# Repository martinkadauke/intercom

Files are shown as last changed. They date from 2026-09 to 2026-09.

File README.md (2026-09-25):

# Klingelbox

**An open-hardware door intercom: a brass front flush in the facade, an e-paper touch screen,
two-way talk, and one PoE cable. Built on ESP32, ESPHome and Home Assistant. No camera, ever.**

[Deutsch](README.de.md)

> Status: prototype. The parts are on the bench, the front and the box exist as 3D-printed
> prototypes. Nothing is installed at a door yet. State of this page: 24 September 2026.

<p align="center">
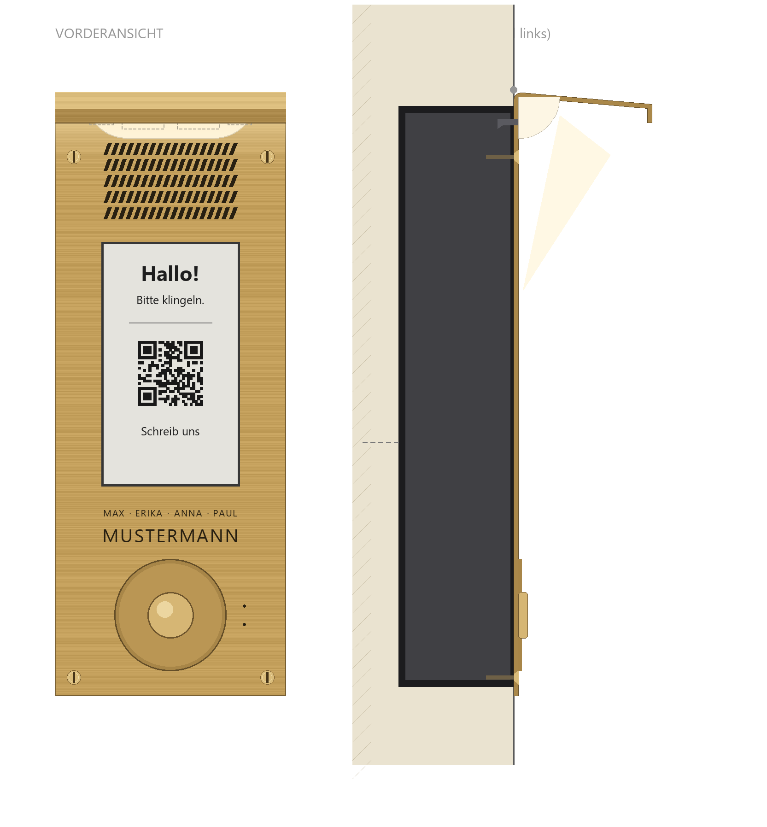
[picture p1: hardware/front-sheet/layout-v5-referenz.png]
Front view and side section of the brass front: speaker grille, portrait e-paper screen, engraved names, round brass button, folded rain roof with a light band
  
</p>

## What it is

- **A doorbell first.** A plain brass button on a supervised line: idle, pressed and a cut wire
  read as three different voltages, so a broken wire is reported instead of going silent. The
  ring reaches the phone before anything else happens at the door.
- **A screen at the door.** A 4.7" e-paper touch screen behind a window in the brass: greetings,
  notices, a QR code. It keeps its image without power and stays readable in sunlight.
- **Talk.** A microphone and a speaker behind the brass for two-way conversation, relayed
  through Home Assistant to a phone. Planned: voice messages and push-to-talk into the house.
- **One cable.** Data and power arrive over a single outdoor PoE cable. No power supply at the
  door, no switch in the box.
- **Local.** Everything runs on ESPHome and Home Assistant at home.
- **Private by design.** No camera. The microphone only opens after a visitor presses
  something, and the screen says so.

## Explore it

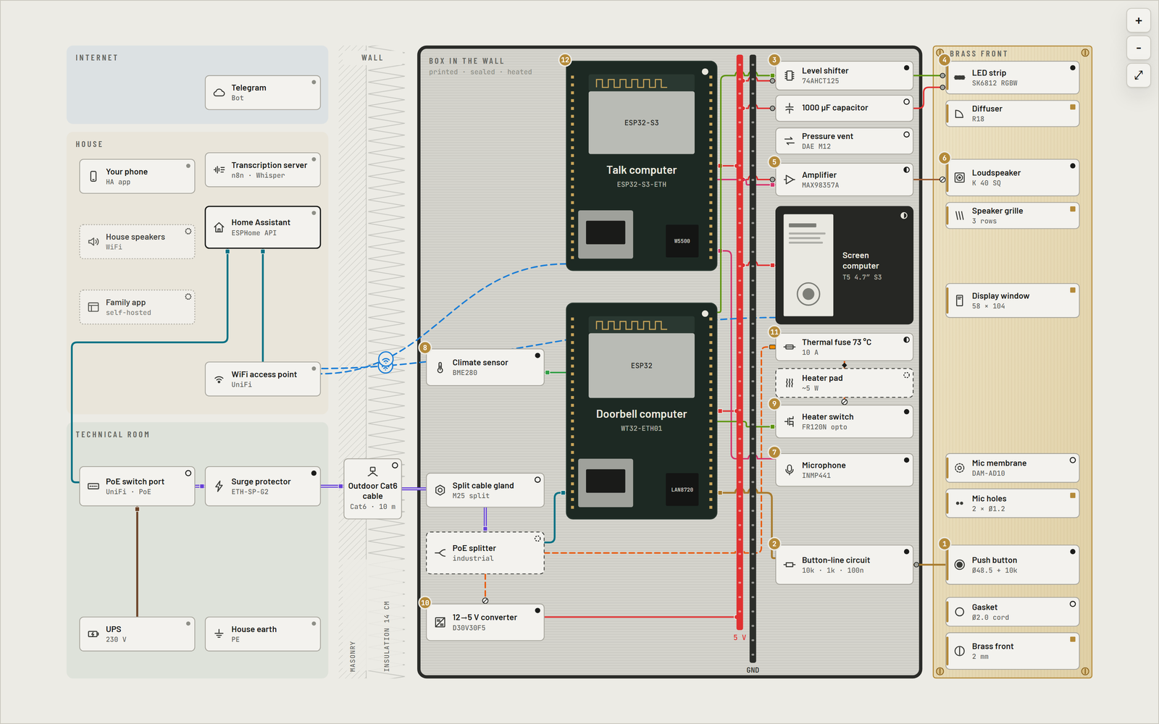
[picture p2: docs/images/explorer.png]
The explorer: every part of the intercom from the house network through the wall into the box and the brass front, with colour-coded wires


The [explorer](explorer/) is an interactive map of the whole system: switch wire types on and
off, tap any part for what it is and why it was chosen, and follow walkthroughs of a ring, the
power path, winter heating and a call. Download
[`explorer/dist/klingelbox-explorer.html`](explorer/dist/klingelbox-explorer.html) and open it in
a browser. A hosted version is planned.

## How it works

Three small computers share one cable and one 5 V rail, and nothing else:

| Computer | Board | Link | Job |
|---|---|---|---|
| Doorbell | WT32-ETH01 | wired | button line, light, heater, climate sensor |
| Talk | Waveshare ESP32-S3-POE-ETH | WiFi | microphone, amplifier, calls |
| Screen | LilyGO T5-4.7-S3 Touch | WiFi | e-paper touch screen |

The bell runs on its own board with stock ESPHome only, so a crash or an update in the audio code
can never silence it. Details, power budget and the winter heater: [docs/architecture.md](docs/architecture.md).

## Repository

| Path | What |
|---|---|
| [`docs/architecture.md`](docs/architecture.md) | how it works, power, winter, talk, mechanics |
| [`docs/bom.md`](docs/bom.md) | what to buy, with the traps (fake "touch" listings, copper-clad cable) |
| [`docs/roadmap.md`](docs/roadmap.md) | the milestones from parts on the desk to the door, and the decisions still to lock in |
| [`docs/build-log.md`](docs/build-log.md) | what happened so far, including the dead ends |
| [`docs/family-app.md`](docs/family-app.md) | the planned self-hosted app for the household |
| [`hardware/`](hardware/) | front sheet, box and diffuser: generator scripts, STL and STEP, part drawings |
| [`explorer/`](explorer/) | the interactive map and its build |
| [`tools/`](tools/) | the privacy scan that runs before every push |

Firmware (ESPHome YAML) and the Home Assistant automations will be added once they have
passed the bench tests.

## Safety

- The surge protector only protects when it is earthed. That, and anything on 230 V, is a job
  for an electrician.
- The e-paper panel is rated 0 to +50 °C. Outdoors it needs the heater, and the heater needs
  its thermal fuse.
- Never plug a board's USB into a computer while the box's 5 V rail is live, unless the cable
  blocks power.

## Licences

- Code (scripts, explorer, firmware): [MIT](LICENSE)
- Hardware designs (CAD scripts, STL, STEP, drawings): [CERN-OHL-P-2.0](LICENSES/CERN-OHL-P-2.0.txt)
- Documentation and images: [CC BY 4.0](LICENSES/CC-BY-4.0.txt)

Designed and written with [Claude Code](https://claude.com/claude-code).

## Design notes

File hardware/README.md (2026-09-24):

# Hardware

Everything physical: the brass front, the box in the wall, the diffuser and dimensioned drawings
of the bought parts. All models are generated by scripts, so dimensions live in code, not in
hand-edited meshes.

## Folders

| Folder | What |
|---|---|
| [`front-sheet/`](front-sheet/) | `make_layout_v5.py` draws the front at true scale (1 unit = 1 mm): a dimensioned SVG, a reference PNG and a detail of the fold. The SVG also carries the engraving, which the CAD reads. |
| [`cad/`](cad/) | FreeCAD scripts. `kasten_v3_params.py` is the single source of dimensions for box and front; `make_kasten_v3.py` builds the box and carrier plate, `make_diffusor_v1.py` the diffuser, `make_sheet_v5.py` the front sheet. |
| [`models/`](models/) | Exported STL (for printing) and STEP (for CAD and metal shops). |
| [`parts/`](parts/) | Dimensioned drawings of bought parts, from datasheets and community measurements. |

## Models

| File | Part | Print notes |
|---|---|---|
| `models/front-sheet-v5.step` | brass front, master | send this to a metal shop (2 mm brass, laser-cut, folded) |
| `models/front-sheet-v5_print.stl` | front, one piece, back on the bed | needs a bed diagonal of about 260 mm |
| `models/front-sheet-v5_print_front.stl` + `_roof.stl` | front split in two, with a lap joint and pegs | both fit side by side on a 256 × 256 bed |
| `models/box-v3_print.stl` | box that sits in the facade | ASA |
| `models/carrier-plate-v3_print.stl` | plate the electronics mount on | ASA |
| `models/diffuser-v1.step`, `diffuser-v1_print.stl` | quarter-round light diffuser | translucent filament |
| `models/diffuser-test-plate.stl` | test plate for the diffuser fit | |

The CAD comments are in German, as the project was designed in German.

## The engraving is a placeholder

The public front carries **MAX · ERIKA · ANNA · PAUL / MUSTERMANN**. To engrave your own names:

1. Edit `NAMES` and `FAMILY` at the top of `front-sheet/make_layout_v5.py`. Longer surnames are set
   smaller rather than squeezed.
2. Run it (needs Python with Pillow and fontTools; it uses the Segoe UI font that ships with
   Windows, which is **not** included here):
   ```
   python front-sheet/make_layout_v5.py
   ```
3. Rebuild the sheet with FreeCAD's command-line interpreter:
   ```
   cd cad
   freecadcmd build_front_sheet.py
   ```
   The results land in `cad/out/`.

## Measure before you commit

Several parts have dimensions nobody publishes (mounting holes of the display board, the
WT32-ETH01, module heights). The drawings in `parts/` mark them. The box design is on its
third iteration and will change once the real parts are measured.

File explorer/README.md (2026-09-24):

# Explorer

An interactive map of the whole system: every part, every wire type as a switchable layer,
every joint and solder spot, and step-by-step walkthroughs (a ring, the power path, winter,
the light, a call). English and German, light and dark, works on a phone.

**Open it:** download [`dist/klingelbox-explorer.html`](dist/klingelbox-explorer.html) and open
it in a browser. It is one self-contained file; the only outside request is for web fonts.

## How it is built

| File | Role |
|---|---|
| `skeleton.json` | the structure and the single source of truth: zones, wire layers, parts (with status), connections, walkthroughs, solder jobs, open points |
| `layout.json` | where each part sits on the 1600 × 1000 canvas, short type tags, and route hints for wires that need them |
| `texts.json` | the English and German copy for every part, wire, walkthrough and solder job |
| `template.html` | page, styles and the rendering engine (plain JavaScript, no libraries) |
| `build.py` | merges the four into `dist/klingelbox-explorer.html` |

```
python build.py
```

The build checks every reference first (a part without a position, a wire to an unknown part,
a walkthrough step naming a missing wire) and writes nothing if one is broken.

Wires are routed automatically: each connection picks the facing sides of its two parts, ends
are spread along each side, straight runs are preferred, and wires that cross a supply bar hop
over it. Where the automatic route is not good enough, `layout.json` pins the ends or gives
waypoints.

To change the system, edit `skeleton.json` (structure) and `texts.json` (words), then rebuild.

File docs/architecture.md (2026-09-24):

# Architecture

State: 2026-09-24. Prototype stage: parts are on the bench, nothing is installed at the door yet.

The interactive version of this page is the [explorer](../explorer/). It shows every part, wire,
joint and solder spot, and walks through what happens on a ring, in winter, at dusk and during a call.

## The idea in one picture

```
 house network                 technical room                wall           box in the facade          brass front
 ─────────────                 ──────────────                ────           ─────────────────          ───────────
 Home Assistant ── LAN ── PoE switch (on a UPS) ── surge ── one outdoor ── cable ── PoE splitter ─┬─ data ─ doorbell computer ── button, light, heater, sensor
       │                                         protector   Cat6 cable    gland        │         │
       │                                          (earthed)                             │         └─ DC ─── 5 V rail ── talk computer ── mic, amplifier, speaker
       │                                                                                │                        └──── screen computer ── 4.7" e-paper touch
       └──────────────── WiFi access point ~1 m away ···· radio ···· talk + screen computers
```

- **One cable.** A single ready-made outdoor Cat6 cable carries data and power (PoE, about 48 V)
  from the switch into the box. There is no power supply at the door and no switch in the box.
- **Three small computers, each with one job.** They share only power and ground; no signal
  wires run between them.

| Computer | Board | Link | Job |
|---|---|---|---|
| Doorbell computer | WT32-ETH01 (ESP32 + LAN8720) | wired, on the splitter's data port | button line, light, heater, climate sensor, power governor |
| Talk computer | Waveshare ESP32-S3-POE-ETH | WiFi | microphone, amplifier, two-way talk |
| Screen computer | LilyGO T5-4.7-S3 Touch (H716) | WiFi | 4.7" e-paper touch screen behind the brass window |

Why three and not one: the bell is the one function that must never fail. A crash or an update
in the audio code cannot take it down when it runs on its own board with stock ESPHome only.
The e-paper panel is a parallel panel that needs its own driver board anyway.

## The ring path (the part that must always work)

1. The brass button sits on a **supervised line**: 10 kΩ pull-up to 3.3 V, 1 kΩ series resistor,
   100 nF to ground, and a 10 kΩ end-of-line resistor soldered straight across the button.
   That gives three distinct voltages on an analog (ADC1) input:

   | State | Voltage |
   |---|---|
   | idle | about 1.73 V |
   | pressed | about 0.30 V |
   | wire cut | about 3.1 to 3.3 V |

   A cut or corroded wire is reported instead of going silent. The pull-up exists because a
   floating input on the first prototype produced 134 phantom rings in 15 minutes.
2. The doorbell computer samples every 40 ms and confirms a press with a median filter
   (about 80 to 120 ms).
3. It sends the ring event **first**, over the cable, to Home Assistant, which pushes a
   high-priority notification to the phone (target: under 1 second, not yet measured).
4. Only then does the door give local feedback: the light flashes, the screen changes.
   Nothing on the ring path waits for the screen, the talk computer or WiFi.

## Power

| Stage | Detail |
|---|---|
| Switch port | PoE on, switch on a UPS so a short power cut does not stop the bell |
| Surge protector | Ubiquiti ETH-SP-G2 before the outdoor cable; only works when earthed (electrician's job) |
| Splitter | industrial, rated down to -40 °C; output **12 V or 5 V still undecided** |
| 12 → 5 V | Pololu D30V30F5 step-down (only with a 12 V splitter) |
| 5 V rail | lever clamps feed all three computers, the amplifier, the level shifter and the LED strip |
| 3.3 V | made on the doorbell and talk computers for the sensor, the button pull-up and the microphone |
| Heater | about 5 W pad behind the display, through a 73 °C one-shot thermal fuse, switched low-side by an opto-coupled MOSFET module |

**Budget.** The surge protector's datasheet lists 802.3af, which allows 12.95 W at the device.
A ring plus a call with the heater on comes to roughly 12.1 W (an estimate, not measured), so the
doorbell computer runs a **governor**: heater off during calls and for 5 minutes after a press,
LED brightness capped while it heats.

## Winter

The e-paper panel is rated 0 to +50 °C; the box sees frost. A BME280 in the box reads
temperature and humidity. The heater **fails cold**: off at boot, off if the sensor fails,
firmware cut-off around 40 °C, and the thermal fuse as the last line of defence. Below about
+2 °C the screen does not refresh.

## Two-way talk (chosen, not yet proven)

- Software: the community [VoIP Stack for ESPHome](https://github.com/n-IA-hane/esphome-intercom)
  with its Home Assistant integration (via HACS). Home Assistant acts as the SIP router and
  hands the call to the phone.
- Flow: ring → Home Assistant starts a call to the talk computer → the phone gets a notification
  with a talk button → tapping it answers. Receiving the notification never opens a microphone.
- Audio: INMP441 MEMS microphone, MAX98357A I²S amplifier at its lowest gain (100 kΩ from GAIN to
  Vin), VISATON K 40 SQ speaker (82 dB at 1 W / 1 m, rated 0.5 W).
- If the echo cannot be tuned out: walkie-talkie mode with the stack's mute switches.
- **Security:** the stack's SIP endpoint has no authentication or encryption. The door devices
  belong in their own VLAN with a firewall that only lets Home Assistant reach them, and
  auto-answer stays locked off.
- **Privacy:** the microphone only opens after a visitor presses something, it is announced on the
  screen and by the LED colour, nothing is recorded without that. (In Germany, § 201 StGB makes
  recording the spoken word without consent a criminal offence.)

Not designed yet: push-to-talk into speakers inside the house, and voice messages delivered to
a phone as audio plus a local Whisper transcript.

## Mechanics

- **Front:** one 2 mm brass sheet, 100 × 260 mm, with a folded rain roof and drip edge. It is
  held by four slotted brass countersunk screws (M3, DIN 963). Cut-outs: display window, speaker
  grille (3 rows of slanted slots), 2 × Ø1.2 mm mic holes and the button hole (Ø49.5 mm for a
  Ø48.5 mm ring). The LED band sits in the bend: 2 windows for the strip and 2 slits for the
  diffuser's tabs.
- **Box:** 3D-printed (ASA; PETG on open-frame printers, which warp large ASA parts), set flush
  into 14 cm of facade insulation and fixed into the masonry behind it. Gasket cord in a rim groove, pressed by the front. A pressure vent lets it breathe
  into the grille cavity; the grille cavity counts as outside air and has to drain.
- **Cable entry:** a split cable gland (Conta-Clip KDS-KV M25, 25.2 mm hole) with a split
  sealing insert for the 6–7 mm cable, so the ready-made cable with its moulded plug can go
  through.
- **No camera. Ever.** This is a design rule, not an open question.

## Open points

See the "Still open" list in the explorer. In short: splitter voltage, real power draw, pin
assignment on the bench, WiFi signal inside the box, the LED strip type and the screen's touch
chip, and a CAD fix (the grille cavity floor slopes the wrong way).

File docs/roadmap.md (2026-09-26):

# Roadmap

State: 2026-09-26. Generated from `explorer/skeleton.json` and `explorer/texts.json`;
the interactive version is the roadmap section of the [explorer](../explorer/).

`[x]` done · `[~]` under way · `[ ]` to do · `◆` a decision that must be locked in

## Must-lock-ins

- ◆ Lock in: splitter 12 V or 5 V (it decides the heater and its switch) (M1)
- ◆ Lock in: the box's inside size (the 12 V splitter alone is 104 × 82 × 32 mm) (M2)
- ◆ Lock in: full duplex or walkie-talkie, after tuning the echo (M3)
- ◆ Lock in: which extra audio features (voice messages, push-to-talk into the house) (M3)
- ◆ Lock in: flush in the wall (cut into the insulation) or on the wall (printed box inside a brass housing) (M4)
- ◆ Lock in: box material (ABS is here for test boxes; ABS and ASA warp in large parts on an open printer, PETG is the alternative) (M4)

## M0 · Concept and architecture

**Done** · 4 of 4 tasks done

Decide what the device is before buying and printing: the front design, the parts and how they connect.

- [x] Front design v5: one bent brass sheet, 100 × 260 mm, light band under the roof
- [x] Architecture: one PoE cable, three computers (doorbell, talk, screen)
- [x] Parts chosen and drawn with their dimensions
- [x] This map and the public repository

*Done when:* Every part, wire and open decision is on the map.

## M1 · All hardware on the table

**Now** · 1 of 5 tasks done

Nothing can be measured, fitted or programmed for real until every part of the final build is here.

Needs: M0 Concept and architecture

- [ ] ◆ Lock in: splitter 12 V or 5 V (it decides the heater and its switch)
- [ ] Place the order: cable, cable gland, heater, seals, small parts
- [x] In hand: doorbell and talk computers, microphones, amplifier, speaker, 12→5 V converter, level shifter, climate sensor, heater switch, USB-serial adapter, thermal fuses
- [~] In the mail: the screen computer
- [ ] Bench checks on arrival: touch chip (I²C scan), LED strip really RGBW, heater switch triggers at 3.3 V

*Done when:* Every part of the final build is here and identified.

## M2 · Measure and alpha print

**Next** · 0 of 5 tasks done

Find out whether everything fits before designing the real box: first the parts alone, then with every cable.

Needs: M1 All hardware on the table

- [ ] Measure everything the makers don't publish: display mounting holes, board heights, microphone, splitter
- [ ] Count every cable and connector that enters the box
- [ ] Alpha print 1: all parts in place, no cables
- [ ] Alpha print 2: the same with all the internal wiring
- [ ] ◆ Lock in: the box's inside size (the 12 V splitter alone is 104 × 82 × 32 mm)

*Done when:* Every part and every cable fits in a printed box, and the number of cables entering it is final.

## M3 · Bench build and software

**Now** · 0 of 8 tasks done

Wire everything together on the desk and build the software until the experience at the door and on the phone is release quality. The first two steps can start today.

Needs: M1 All hardware on the table

- [ ] Phone side first: answer a test call from a notification (no door hardware needed)
- [ ] Doorbell on the doorbell computer: all three line states, 20 of 20 presses on the phone in under 1 s
- [ ] (waiting) Screen pages change on a ring; WiFi signal measured in a mock box behind metal (waits for the screen)
- [ ] Talk, one direction at a time (walkie-talkie)
- [ ] ◆ Lock in: full duplex or walkie-talkie, after tuning the echo
- [ ] ◆ Lock in: which extra audio features (voice messages, push-to-talk into the house)
- [ ] (waiting) One cable, power rail, heater and its power limit; measure the real PoE draw (waits for the splitter)
- [ ] UX until release quality: screen pages, light, sounds, the flow on the phone

*Done when:* The desk setup does everything at release quality, and the measured power stays within 802.3af.

## M4 · Watertightness proof of concept

**Now** · 0 of 7 tasks done

Prove that the printed box, a steel bracket and a metal plate can be sealed, whichever way the box is mounted. Exploratory: it runs alongside everything else.

Needs: M0 Concept and architecture

- [ ] ◆ Lock in: flush in the wall (cut into the insulation) or on the wall (printed box inside a brass housing)
- [ ] Design and source the steel bracket the brass plate screws onto
- [ ] Test plate: flat, no bends, no engraving, but the real cut-outs
- [ ] Seals: 2 mm gasket cord, button O-ring, mic membranes, cable gland, pressure vent
- [ ] ◆ Lock in: box material (ABS is here for test boxes; ABS and ASA warp in large parts on an open printer, PETG is the alternative)
- [ ] The grille cavity drains outwards (the CAD slope is currently the wrong way round)
- [ ] Water test of a sealed test box: hose or shower, dry inside afterwards

*Done when:* A test box with bracket and test plate stays dry inside in a repeatable water test, and the sealing recipe is written down.

## M5 · Beta box on the desk

**Later** · 0 of 4 tasks done

The complete device in its real box, with the steel bracket and a dummy plate, running on the desk over Ethernet. Not watertight yet.

Needs: M2 Measure and alpha print, M3 Bench build and software, M4 Watertightness proof of concept (bracket and dummy plate)

- [ ] Print the beta box from what the alpha prints showed
- [ ] Fit the steel bracket and a dummy plate (flat, same cut-outs)
- [ ] All inside wiring finished; the wiring to the outside is settled
- [ ] Two weeks on the desk over Ethernet: scripted rings and calls, 20 PoE power cycles, no unexpected reboot of the doorbell computer

*Done when:* The whole device runs in its box for two weeks without a surprise.

## M6 · Pre-release box

**Later** · 0 of 5 tasks done

Bring the sealing lessons into the proven beta design and order the real brass front.

Needs: M5 Beta box on the desk, M4 Watertightness proof of concept

- [ ] Apply the sealing recipe to the beta design
- [ ] Order the real brass front from a metal shop (laser-cut, bent, engraved)
- [ ] Final print in the chosen material
- [ ] Water test of the complete device
- [ ] Freezer cold start: heater, screen and splitter come up in frost

*Done when:* The finished device passes the water test and the cold start.

## M7 · At the door

**Later** · 0 of 4 tasks done

Install the finished device at the front door and switch it on for good.

Needs: M6 Pre-release box

- [ ] Electrician: earth the surge protector, remove the old bell transformer
- [ ] Cable route through the wall
- [ ] Mount the box and seal the joint to the facade
- [ ] Go live with the watchdogs on (stuck button, cut wire, offline)

*Done when:* A ring at the real door reaches the phone.

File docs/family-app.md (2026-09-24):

# The family app (planned, nothing built yet)

The door is not meant to be configured through YAML files forever. The plan is a small,
self-hosted web app that the household uses day to day, while Home Assistant stays the
automation hub underneath.

## What it should do

- **Screen notices:** put a message on the door's e-paper screen ("Back in 20 minutes",
  "Parcels please to the neighbours"), with an expiry time.
- **Chimes:** choose the ringtone that plays on the speakers inside the house, and its volume,
  per room and per time of day.
- **Silence:** a quiet mode that routes rings to a quiet notification channel.
- **Other home systems and speakers:** one interface instead of several apps.
- **Talk (later):** could host the relay for live push-to-talk from the door into the house.

## How it connects

```
 household (browser / phone) ──► family app ◄──► Home Assistant ◄──► door computers (ESPHome)
                                      ▲                 │
                                      └── status & ─────┘
                                          control API
```

- The app exposes an **API and a Home Assistant integration**, so every setting it owns is also
  visible to automations (status and control).
- The door firmware keeps its settings reachable over ESPHome entities and services instead of
  burying them in firmware. That is a constraint on the firmware today, even though the app
  comes later.
- Self-hosted, no cloud dependency; accounts only for the household.

## Open questions

- Framework and hosting (it will run next to Home Assistant on the home server).
- Whether the push-to-talk relay lives in the app or in Home Assistant.
- How screen notices avoid telling strangers that nobody is home.

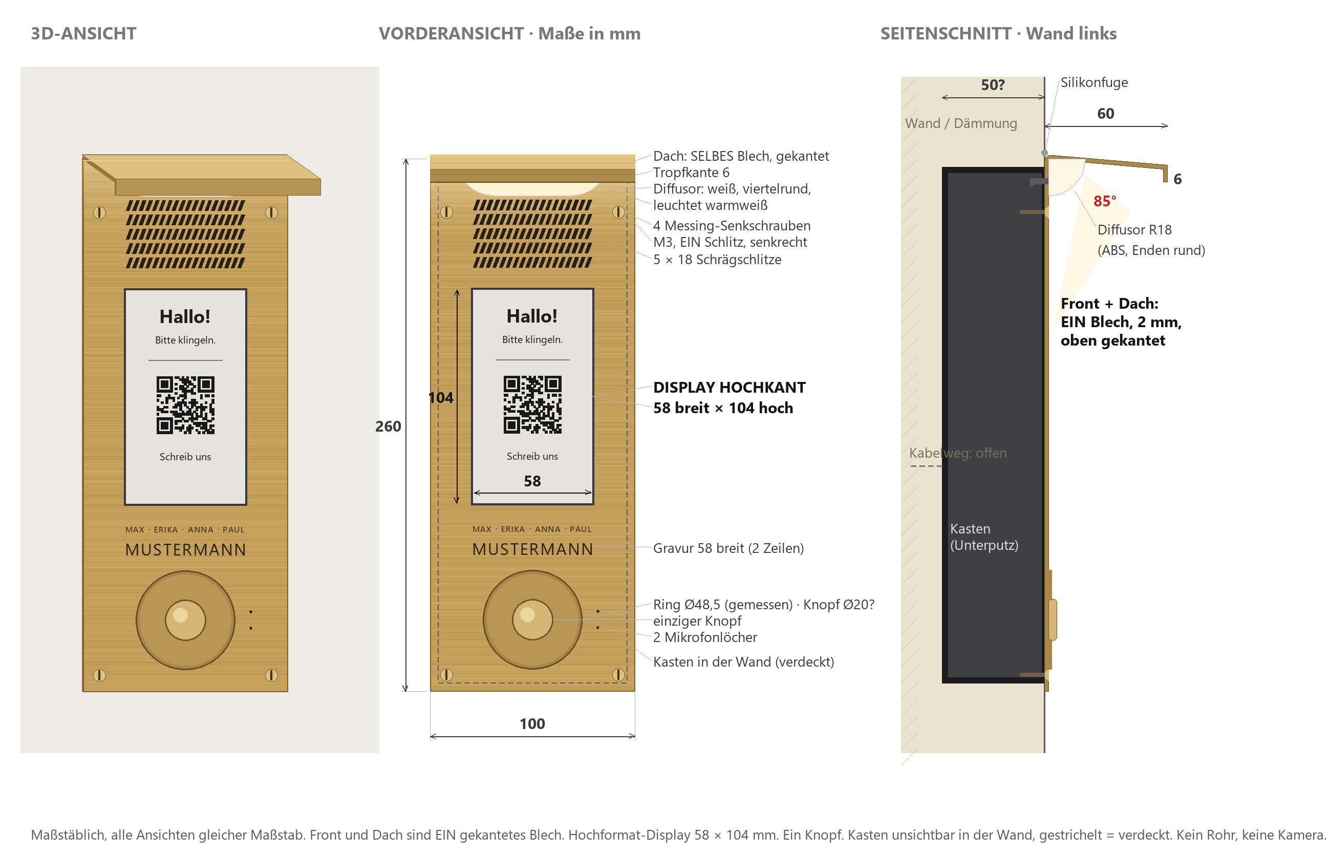
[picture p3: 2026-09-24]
hardware/front-sheet/gemini-zeichnung-v5.png

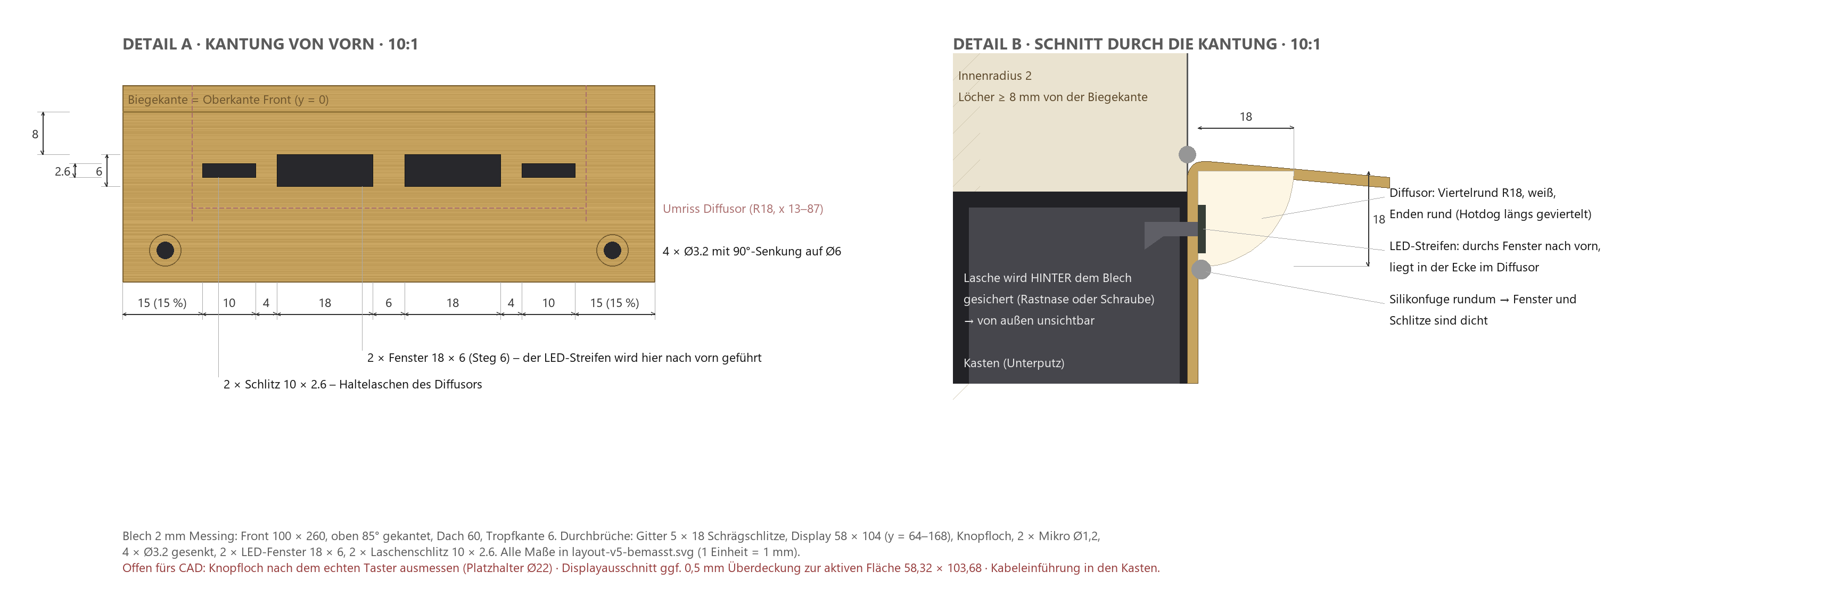
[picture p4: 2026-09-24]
hardware/front-sheet/detail-kantung-v5.png

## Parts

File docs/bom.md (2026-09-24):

# What to buy (bill of materials)

State: 2026-09-24. Prices are gross, from German/EU shops, and were read off the product pages on
that date. "Pending" means the choice is not made yet; do not buy those blind.

Parts marked **measure** have dimensions the maker does not publish. The drawings in
[hardware/parts](../hardware/parts/) show what is known and what still has to be measured.

## Indoors: network and power

| Qty | Part | Why | Notes |
|---|---|---|---|
| 1 | PoE switch port, 802.3af or better | data + power down one cable | put the switch on a UPS |
| 1 | Ubiquiti ETH-SP-G2 surge protector | protects the house network from the outdoor cable | **must be earthed by an electrician**; datasheet lists 802.3af only |
| 1 | Short patch cable | switch → surge protector | |

## Through the wall

| Qty | Part | Why | Notes |
|---|---|---|---|
| 1 | Ready-made outdoor Cat6 cable, goobay **55432** (10 m) | the one cable | solid copper AWG 24/1, U/UTP, double PE jacket, UV-resistant, -40 to +75 °C, outer Ø 6.0–6.6 mm; about €11–13. **Not** goobay 94389: almost the same title, but copper-clad aluminium |
| 1 | Split cable gland Conta-Clip KDS-KV M25 BK (28611.4) | lets the moulded plug through, then seals | lock nut included; Conta-Clip gives a **25.2 mm** hole; IP66 |
| 1 | Split sealing insert Conta-Clip KDS-DE 6-7 BK (28526.4) | seals around one 6–7 mm cable | measure your cable: 5-6 BK (28525.4) and 7-8 BK (28527.4) are the neighbours. Use BK (UV-stabilised), not GR |

## In the box: power

| Qty | Part | Why | Notes |
|---|---|---|---|
| 1 | Industrial PoE splitter, rated down to -40 °C | separates data and power | **pending** — see below |
| 1 | Pololu D30V30F5 step-down 12 → 5 V, 3.4 A | 5 V rail | only with the 12 V splitter |
| 1 set | Lever clamps (WAGO 221) | 5 V and ground distribution | |
| 1 | Short Cat6 patch cable, 0.25 m, copper | splitter → doorbell computer | some cheap 0.25 m cables are CCA too |
| 1 | USB-C plug to 2-pin screw terminal (VBUS/GND only) | 5 V into the screen computer | no data lines, no CC resistor: fine for feeding power *into* the board; check polarity first |
| 2 | Resettable PTC fuse, 0.5 A hold (e.g. FREI PFRA 050) | protects the rail from the LED branch | 0.5 A covers the ~4 LEDs used |
| 2 | 1000 µF / 25 V low-ESR and 10 µF electrolytic capacitors | at the LED strip and at the amplifier | stripe = minus |

**The splitter decision**

| | 12 V: TRENDnet TI-SG104 | 5 V: Waveshare industrial PoE splitter |
|---|---|---|
| Price seen | about €69–70 | €33.99 (DC plug) |
| Temperature | -40 to +75 °C | -40 to +85 °C |
| Size | 104 × 82 × 32 mm | 102.5 × 29.6 × 24.8 mm |
| DC output | 4-pin screw terminal | pigtail with a DC barrel plug (reviews disagree whether it is 5.5 × 2.1) or a USB-C variant |
| Power from 802.3af | 10.2 W at 12 V (TRENDnet's figure for version 2) | not stated |
| Heater switch | the opto-coupled FR120N module works (12 V gate drive) | needs a logic-level, non-isolated module (3.3–20 V trigger); opto-isolated "D4184" boards have the same gate problem as the FR120N |
| Heater | 12 V pad | 5 V polyimide foil (about 4.2 W, 0.84 A on the 5 V rail) |

## In the box: the three computers

| Qty | Part | Why | Notes |
|---|---|---|---|
| 1 | WT32-ETH01 (ESP32 + LAN8720 + RJ45) | doorbell computer, wired | about €20; no USB: flash it once over serial |
| 1 | USB-to-serial adapter, 3.3 V logic (e.g. CP2102 or CH340G) | first flash of the WT32-ETH01 | |
| 1 | Waveshare ESP32-S3-POE-ETH | talk computer, on WiFi | about €25–32; its plug-on PoE module is only for desk tests |
| 1 | LilyGO T5-4.7-S3 **Touch** (SKU H716) | screen computer + 4.7" e-paper, 960 × 540 | about €55 at OpenELAB; several marketplace listings with a touch photo are **not** touch versions; **measure** the mounting holes |

## Audio

| Qty | Part | Why | Notes |
|---|---|---|---|
| 1 | INMP441 I²S MEMS microphone module | voice at the door | 3.3 V only; the labelled side (sound hole) faces the membrane |
| 1 | Adafruit MAX98357A I²S amplifier | drives the speaker | set to 3 dB: 100 kΩ from GAIN to Vin (GAIN to ground is 12 dB, louder); 10 µF + 0.1 µF at its supply |
| 1 | VISATON K 40 SQ, 8 Ω, IP65/67 front | speaker behind the grille | 40 × 40 mm, Ø35 cut-out, 11.5 mm deep, 4 × Ø3.4 on 32 × 32; about €5.50 |
| 1 pack | Self-adhesive PTFE vent membrane B+B Thermo-Technik DAM-AD10 (12 pcs) | keeps water out of the mic holes | 10.2 mm outer, **5.5 mm active**: one membrane per mic hole. Sold as a pressure vent: test voice quality through it |

## Light, sensor, heater

| Qty | Part | Why | Notes |
|---|---|---|---|
| 1 | SK6812 RGBW LED strip, 5 V, ~4 LEDs used | light under the roof + status colours | a real white channel helps; **measure** height |
| 1 | SN74AHCT125N (DIP-14) + DIP-14 socket + 330 Ω | lifts the 3.3 V LED data to 5 V | cheap insurance against flaky LEDs in the cold |
| 1 | BME280 module (with humidity) | box temperature and humidity | many "BMP280" boards look the same: check the chip ID (0x60) |
| 1 | Heater for the 12 V path: silicone pad 12 V / 5 W, Ø50 mm — or a self-adhesive PTC foil 12 V / 3 W, 47 × 60 mm | keeps the e-paper above 0 °C | the silicone pad listing shows no adhesive, and acrylic tape bonds poorly to silicone; the PTC foil limits its own temperature |
| 1 | Thermal fuse 73 °C | one-shot overheat cut-off | soldering heat can blow it: clamp the leads in WAGO 221 clamps or crimp them with uninsulated butt connectors |
| 1 | Opto-coupled MOSFET module (FR120N type) | switches the heater | 12 V path only |
| – | Thermally conductive double-sided tape | only if the heater is not self-adhesive | |

## Button line

| Qty | Part | Why | Notes |
|---|---|---|---|
| 1 | A plain (dumb) brass push button, no electronics | the doorbell | the prototype uses a Ø48.5 mm ring |
| 2 | 10 kΩ resistor | pull-up + end-of-line at the button | the end-of-line one is soldered across the button contacts |
| 1 | 1 kΩ resistor, 1 × 100 nF capacitor | series resistor and filter | on perfboard |
| – | Adhesive-lined heat shrink | seals the joint behind the button | |

## Enclosure and front

| Qty | Part | Why | Notes |
|---|---|---|---|
| – | Filament for the box: ASA, or PETG | box and carrier plate | ASA is more UV-resistant, but Bambu Lab advises against large or dense ASA/ABS parts on the open-frame A1; PETG is the A1-friendly option |
| – | Translucent filament | diffuser | |
| – | PLA | front-sheet prototype | the final front is brass |
| 1 | 2 mm brass sheet, laser-cut and folded by a metal shop | the final front | from [the front-sheet STEP](../hardware/models/front-sheet-v5.step); only after the bench tests pass; have the countersinks done there (at least 1.7 mm deep) |
| 4 | M3 × 8 countersunk brass screws, single slot (DIN 963) + M3 heat-set inserts (6 mm long) | hold the front | M3 × 8 matches a 6 mm insert under a 2 mm sheet; M3 × 10 needs a 2 mm deeper hole |
| 1 | Pressure vent M12 × 1.5 (AGRO 595.15.AS, -40 to +100 °C, or Bopla DAE M12) + M12 × 1.5 lock nut | the sealed box breathes | vents into the grille cavity; Bopla: 12.2 mm hole + nut for walls under 3 mm, a printed M12 thread for thicker walls |
| – | Round gasket cord Ø2.0 mm, **solid** EPDM (not foam), about 1–2 m | rain seal between box and front | ends glued into a ring; a 2.0 mm cord fills a 2.4 × 1.5 mm groove to about 87 %, so a slightly wider groove is better |
| 1 | O-ring 26 × 2 mm (EPDM or NBR) | seals the button | use silicone grease, not mineral grease (EPDM swells) |
| – | Silica gel sachets | buffer against condensation | the vented box saturates them: replace now and then |
| – | Neutral-cure silicone | around the diffuser | acetic-cure silicone corrodes brass |
| – | Conformal coating (e.g. Kontakt Chemie PLASTIK 70) | protects the boards | rated only to +60 °C continuous: keep it away from the heater; mask the mic, the sensor, sockets and clamps |

## Tools and consumables

Solder with flux, perfboard, female pin headers (to plug modules instead of soldering them in),
nylon standoffs, wire ferrules and crimper, 22 AWG silicone wire, Kapton tape, isopropyl
alcohol, a multimeter, and a real USB-C data cable for flashing the S3 boards.

## Optional

| Qty | Part | Why |
|---|---|---|
| 1 | Home Assistant Voice PE (+ USB-C 5 V / 3 A supply, not included) | a chime inside the house |

## Not needed any more (so you do not buy them by mistake)

- A power supply in the technical room, passive PoE injector sets, a separate DC cable.
- Field-installable RJ45 plugs and cable rolls: the ready-made outdoor cable replaces them.
- A switch inside the box (only if WiFi calls fail the in-box test).

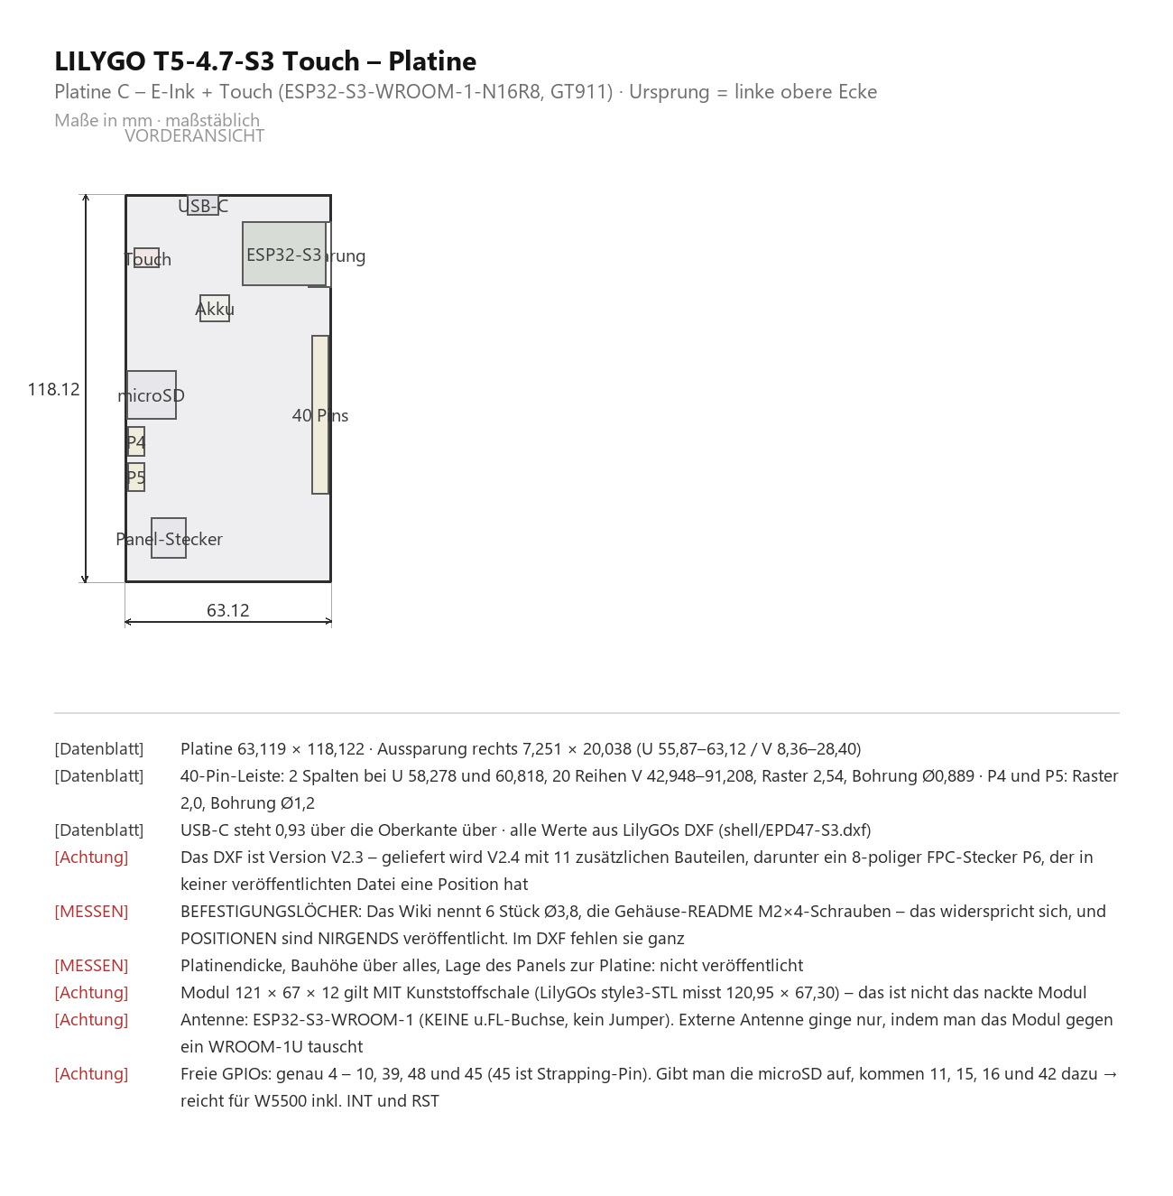
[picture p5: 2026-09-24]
hardware/parts/display-pcb.png

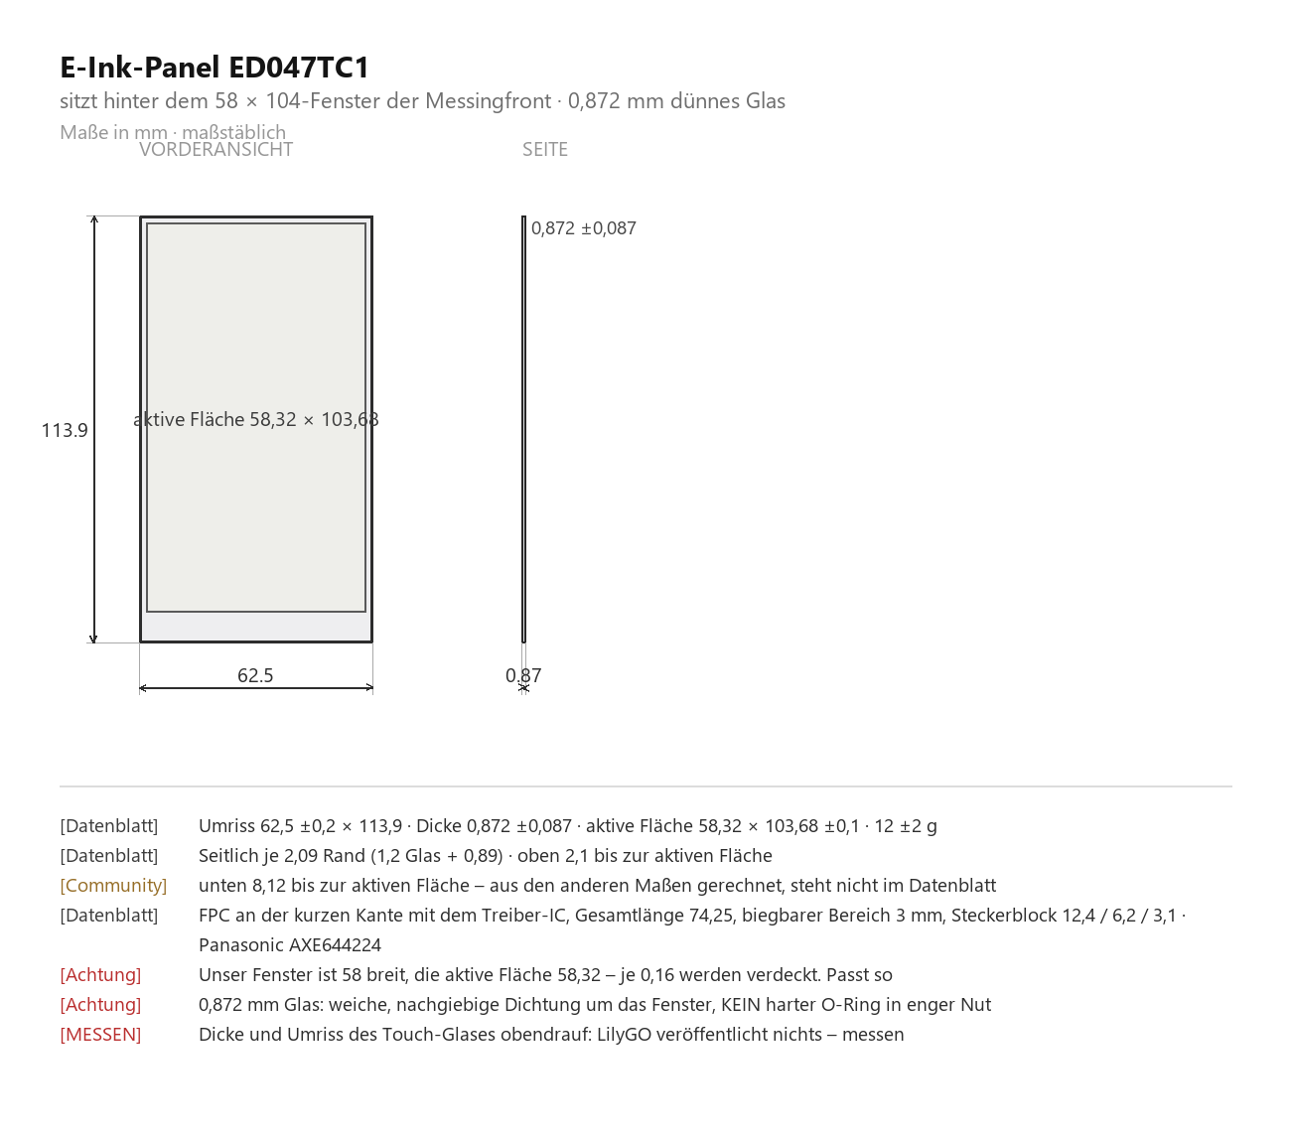
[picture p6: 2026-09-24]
hardware/parts/display-panel.png

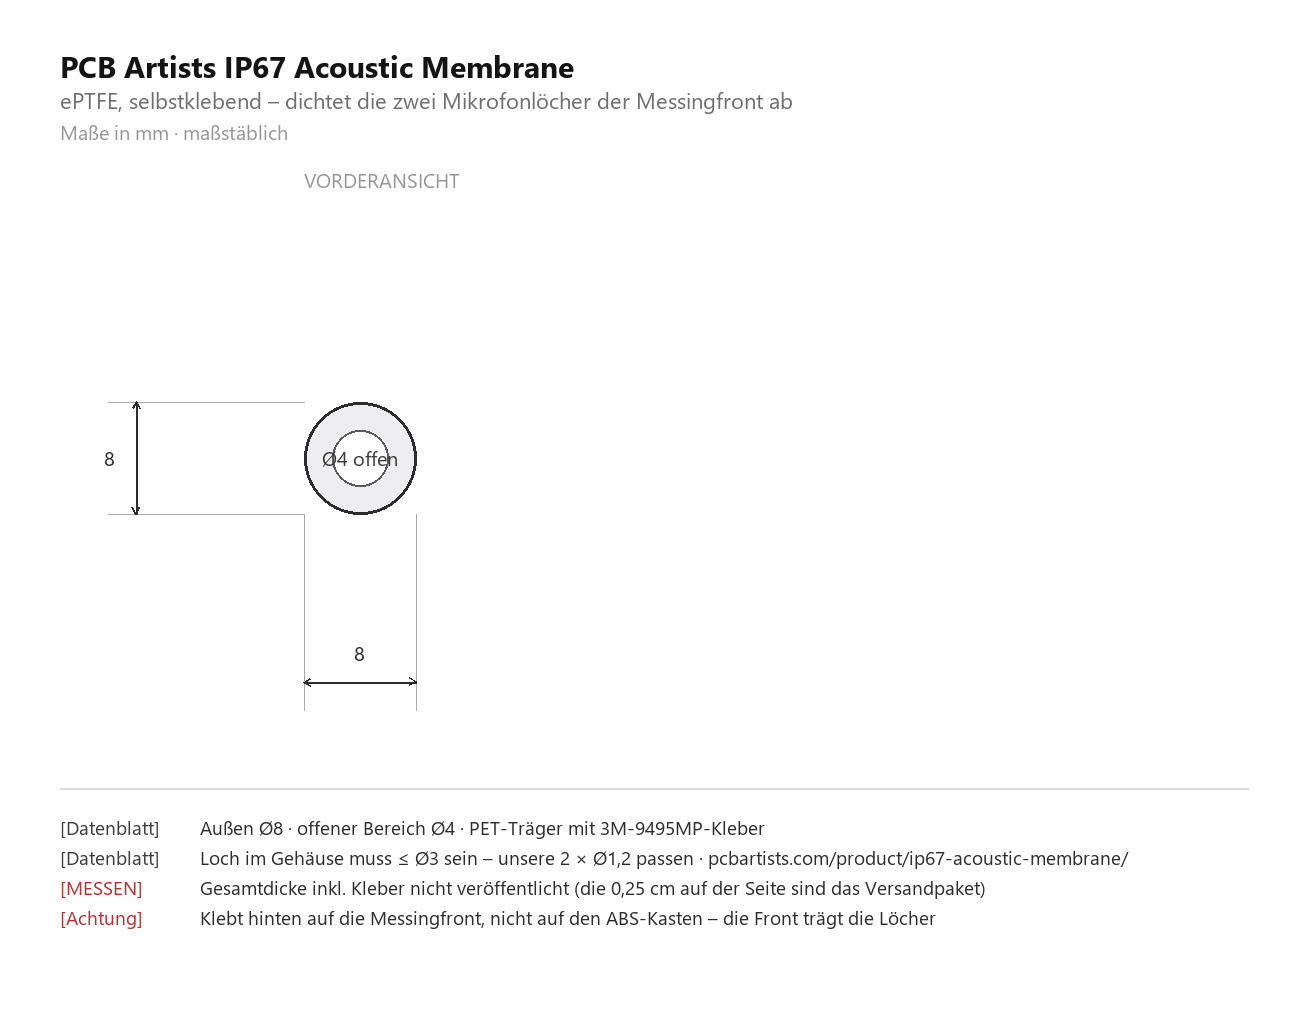
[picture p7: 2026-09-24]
hardware/parts/membran-ip67.png

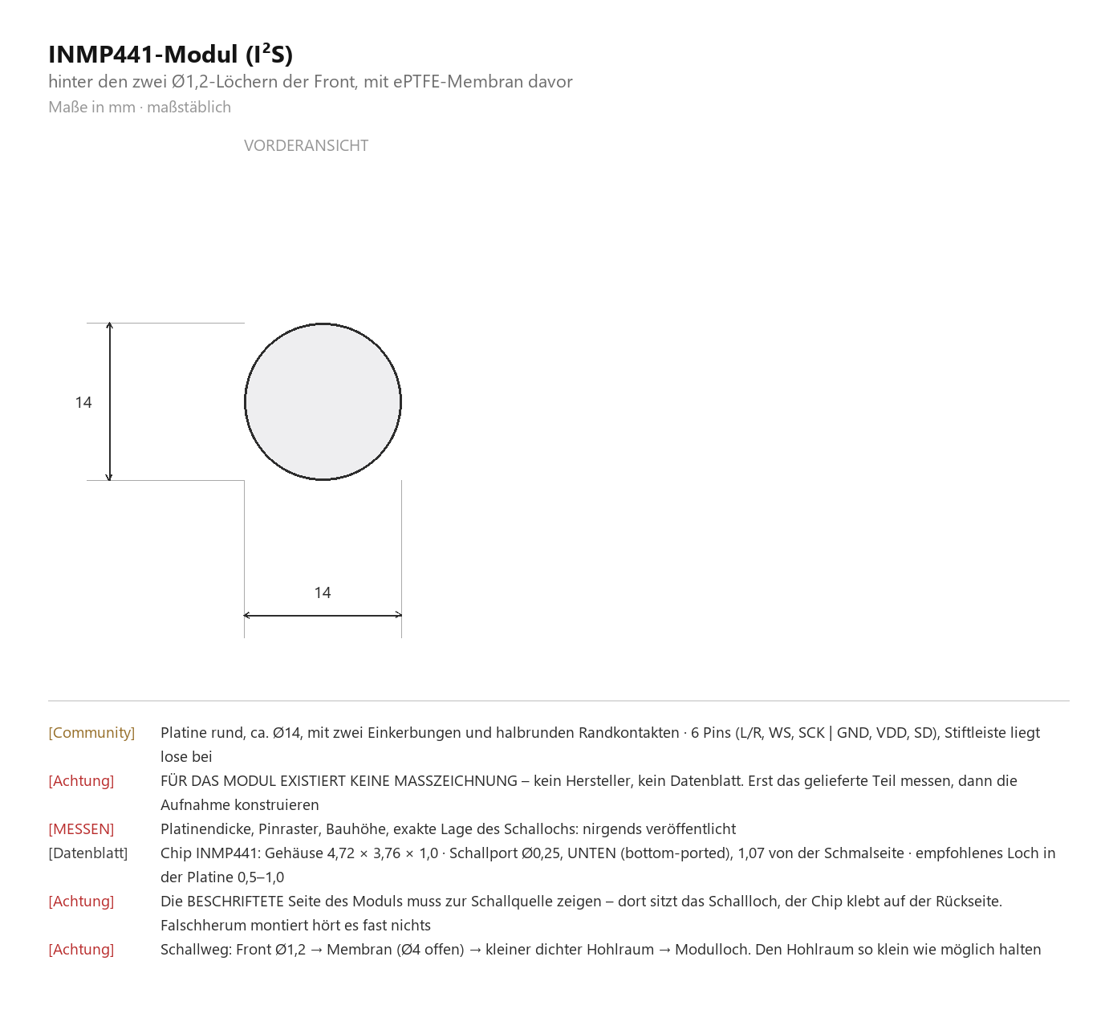
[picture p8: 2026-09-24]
hardware/parts/inmp441.png

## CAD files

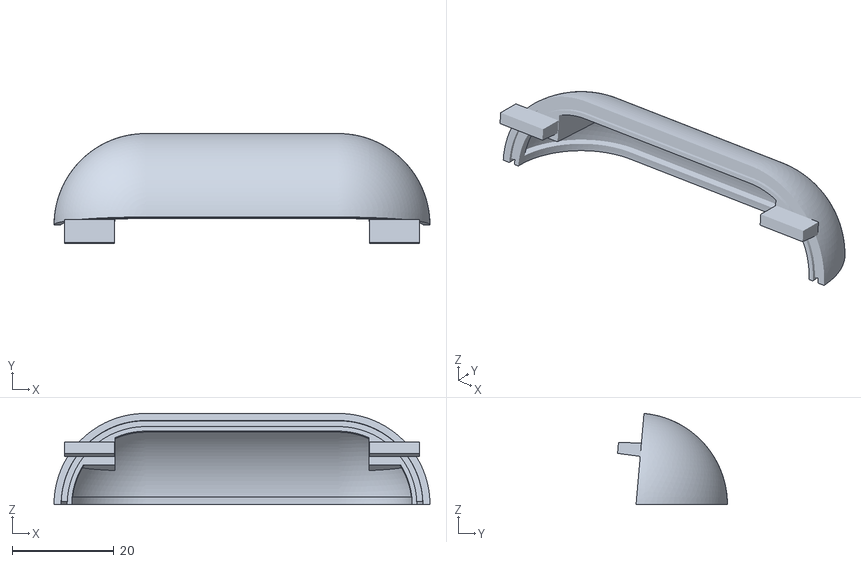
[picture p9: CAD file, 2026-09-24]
hardware/models/diffuser-v1_print.stl
74.0 x 21.6 x 17.9

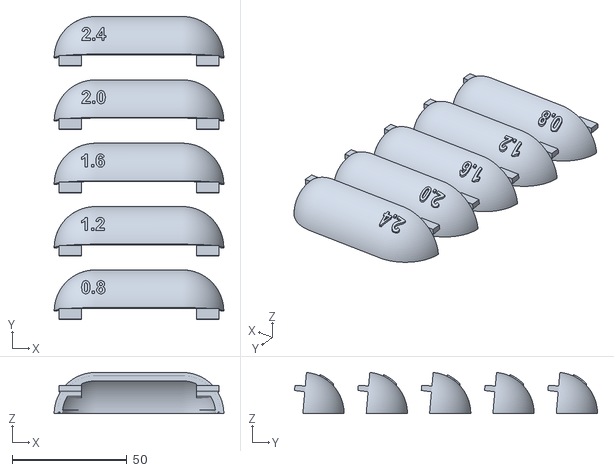
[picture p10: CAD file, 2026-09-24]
hardware/models/diffuser-test-plate.stl
74.0 x 132.2 x 17.9

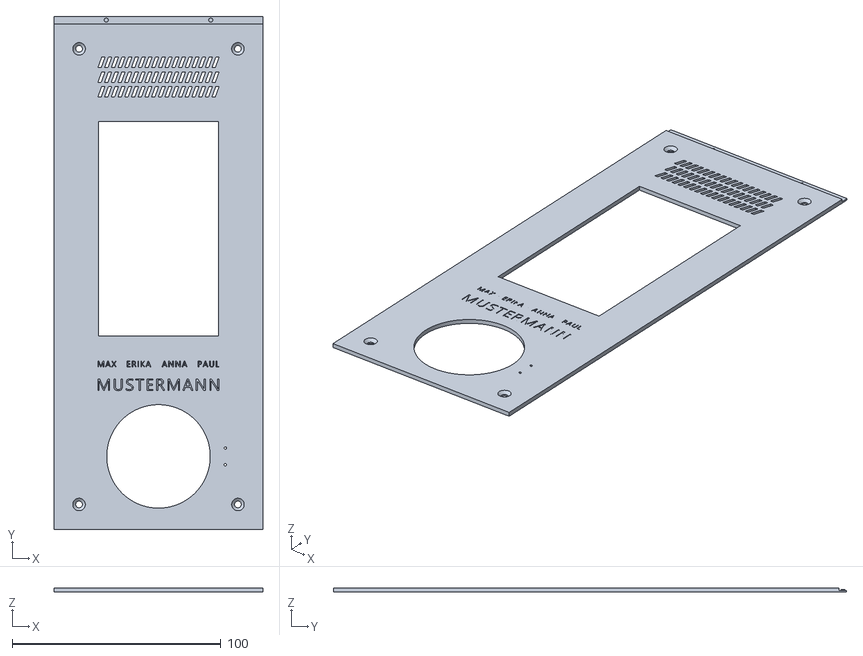
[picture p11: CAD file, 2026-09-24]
hardware/models/front-sheet-v5_print_front.stl
100.0 x 245.5 x 2.00

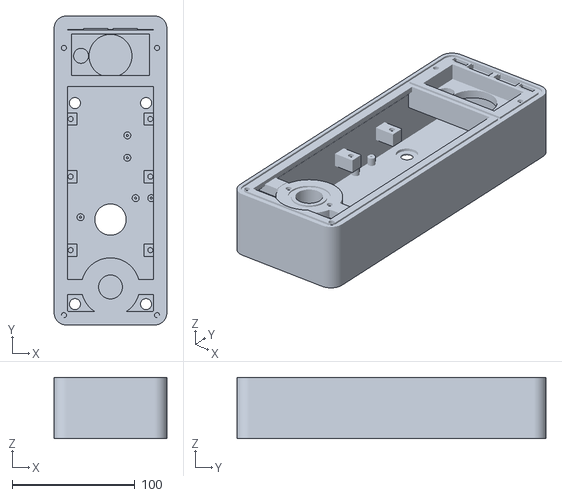
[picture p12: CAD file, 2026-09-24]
hardware/models/box-v3_print.stl
92.0 x 252.0 x 50.0

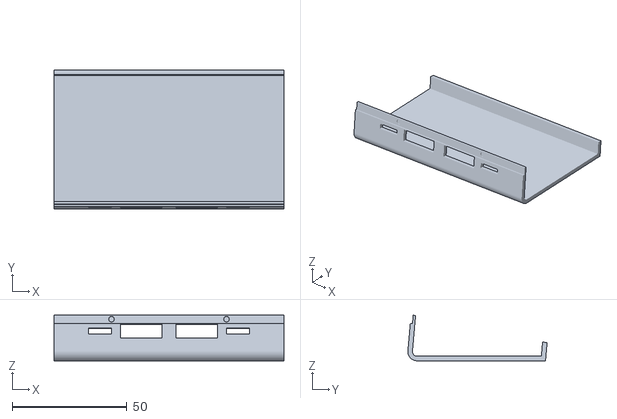
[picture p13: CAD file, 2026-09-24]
hardware/models/front-sheet-v5_print_roof.stl
100.0 x 60.6 x 19.8

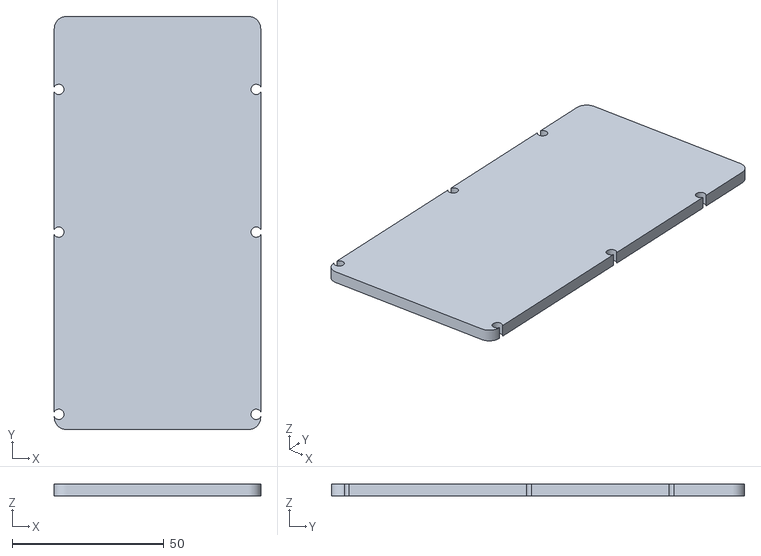
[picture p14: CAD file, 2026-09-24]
hardware/models/carrier-plate-v3_print.stl
68.0 x 136.0 x 4.00

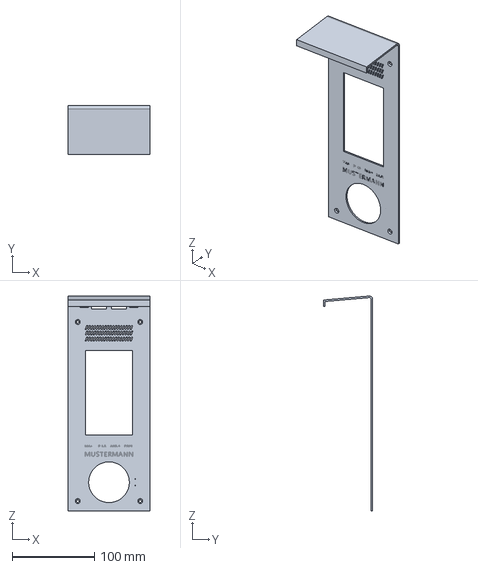
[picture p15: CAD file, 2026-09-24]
hardware/models/front-sheet-v5.step
100.0 x 60.0 x 261.6 mm

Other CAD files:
hardware/models/diffuser-v1.step
hardware/models/front-sheet-v5_print.stl

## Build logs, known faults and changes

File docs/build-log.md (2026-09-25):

# Build log

What happened, in order, including the dead ends. Dates are 2026.

## August: a doorbell that works

- The old doorbell had been dead for a long time: its button's circuit board had died from rain.
- First version: a plain brass button on an existing two-wire cable into an ESP32 indoors,
  running ESPHome, with a push notification through Home Assistant. No chime.
- **Lesson:** a floating input pin on a long cable acts as an antenna. At one point it
  produced 134 phantom rings in 15 minutes. The fix became the supervised line: pull-up,
  series resistor, filter capacitor and an end-of-line resistor at the button, so idle,
  pressed and a cut wire give three different voltages.
- **Lesson:** a component only does something if current can flow *through* it. A resistor
  plugged into an empty breadboard row changed nothing, and only the multimeter showed it.

## 17 September: from doorbell to intercom

- New goal: a small e-paper screen at the door, later speech in both directions.
- **Hard rule from day one: no camera at the door, ever.**
- Front design in five rounds of dimensioned drawings (generated in Python, true scale):
  - v2: portrait screen, one button, speaker grille;
  - v3: flush in the wall, a separate brass roof cap, a cable pipe bending into the wall;
  - v4: back to one folded sheet, with a brass cable pipe rising in front of the wall (rejected);
  - v5: no pipe, 100 × 260 mm, LED band in the fold with a quarter-round diffuser.

## 18 September: CAD

- The front sheet, the in-wall box, a carrier plate and the diffuser modelled in FreeCAD,
  driven by scripts. First prints of the sheet (in two parts, it is taller than the print bed)
  and the box.
- The speaker changed from a 3 W waterproof part to the smaller VISATON K 40 SQ: it is quieter on
  paper (0.5 W) but louder in practice (82 dB vs 74 dB at 1 W / 1 m). Sensitivity beats wattage.

## 24 September: parts, architecture, explorer

- Most parts arrived and were identified (some sold under vague names: an opto-coupled MOSFET
  module turned out to be usable because its optocoupler drives the gate from 12 V).
- Architecture settled:
  - **one** ready-made outdoor PoE cable instead of three cables plus a power cable;
  - three computers: a wired doorbell computer, a talk computer on WiFi, a screen computer
    on WiFi;
  - two-way talk via the community VoIP Stack for ESPHome, with walkie-talkie mode as the
    fallback.
- The [explorer](../explorer/) was built to make the whole system understandable, including
  every wire and every solder joint.

## Next

The plan from here is the [roadmap](roadmap.md): all hardware on the table, measure and
alpha-print the box, build the software on the bench, prove the box can be sealed, then a beta
box on the desk, a pre-release box and finally the door.

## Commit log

2026-09-24 Publish the Klingelbox: explorer, hardware, docs
    - Interactive explorer (EN/DE): every part, wire layer, joint and solder spot,
    walkthroughs; built from skeleton/layout/texts JSON by build.py
    - Hardware: front-sheet layout generator and FreeCAD scripts for front, box,
    carrier plate and diffuser; STL and STEP exports; dimensioned part drawings.
    The engraving is a placeholder (MUSTERMANN); long surnames now shrink
    instead of overlapping
    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
    [box-v3_print.stl, carrier-plate-v3_print.stl, diffuser-test-plate.stl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]
2026-09-24 Refine the BOM from verified sources; fix O-ring and gland details
    - BOM: exact parts where they were verified (goobay 55432 dimensions,
    KDS-DE 6-7 insert, PTC fuse, USB-C terminal lead, M3 x 8 screws,
    solid EPDM cord, AGRO/Bopla vent rules), a side-by-side of the 12 V
    and 5 V splitter paths, and a tools list
    - Button O-ring is 26 x 2 (from the CAD), not "42 or 26"
    - Gland hole: Conta-Clip specifies 25.2 mm
    - Filament note: large ASA parts warp on open-frame printers
2026-09-26 Thermal fuses arrived (in the mail -> in hand)
